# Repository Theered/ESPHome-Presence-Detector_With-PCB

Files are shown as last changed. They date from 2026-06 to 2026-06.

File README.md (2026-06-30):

# ESPHome-Presence-Detector_With-PCB
I was tired of my lights constantly turning off whenever I sat still while using a standard PIR motion detector. Since PIR sensors only detect "big movements", they often fail to notice someone who is sitting quietly.

To solve this, I built a presence detector using an mmWave sensor. Unlike a traditional PIR sensor, an mmWave sensor can detect very small movements, such as your chest moving while breathing, allowing it to reliably detect occupancy even when you're not moving around.

While designing the project, I decided to add a few extra features:

* **mmWave presence detection** for reliable occupancy sensing
* **PIR motion sensor** for fast motion detection when entering the room
* **Ambient light sensor** to prevent lights from turning on when the room is already bright
* **Status LED** to indicate Wi-Fi or device issues
* **Custom PCB** to keep the wiring clean and make assembly easier

The PCB connects all modules directly to the microcontroller, making installation as simple as plugging the sensors into their designated headers.

Sensor data is sent to Home Assistant using ESPHome, allowing you to create virtually any automation you can think of —from automatically controlling lights to sending notifications when someone enters a room, everything is possible.

## Requirements

Before starting this project, you will need:

1. A working Home Assistant server
2. A soldering iron and basic soldering skills
3. A bit of patience and a good mood ;)

**Note:** The status LED and its resistor are small and can be quite challenging to solder. If you don't care about the LED, it can be left out.

## PCB Design

schematic:


PCB:


## Design Inspiration

I wanted a clean and modern design for the detector, so i kindly asked chatGPT to make a few diffrent designes and shapes before settling on this final version:

Gemini_Generated_Image_1y6acm1y6acm1y6a

i then started modeling my own...


## Project Status

🚧 This project is still under development.

Additional documentation will be added soon, including:

* Complete assembly guide
* ESPHome configuration- and firmware instalation guide
* refined 3D-printable enclosure files

Thank you for your patience while I finish building and documenting the project.

BOM:
1. ws2812b LED
   

2. TSL2591 IIC I2C Light Sensor
   

3. ESP32 S3 C3 SuperMini Development Board
   

5. HLK-LD2410c module
   

7. AM312 PIR motion detector
   

8. Female Straight Needle Pin Header
   

9. Custom PCB (gerber files are linked in the project)


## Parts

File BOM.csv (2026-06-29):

Name | Purpose | Quantity | Total Cost (USD) | Link | Distributor
PCB | Connecting everything neatly (price includes shipping) | 1 | 4.40 |  | JLCPCB
breakable Pin Header | plugging the modules in | 1 | 2.90 | https://www.aliexpress.com/item/1005007476809536.html | Aliexpress
single ws2812b LED pixel | For showing errors and maby some smarthome integration. Pro tip: can be stolen off led strip, its cheaper | 1 | 1.55 | https://de.aliexpress.com/item/1005002657432751.html?mp=1 | Aliexpress
TSL2591 | mesuring light | 1 | 5.40 | https://www.aliexpress.com/item/1005006343708454.html | Aliexpress
ESP32 C3 SuperMini Development Board | controling the circuit | 1 | 4.40 | https://www.aliexpress.com/item/1005007941259180.html | aliexpress
ld2410c | detecting if someone is in my room reliably without turning off the light when sitting still | 1 | 5.30 | https://www.aliexpress.com/item/1005006153951413.html | Aliexpress
am312 mini | turning light on instantly instead of waiting for the slow mmwave detection | 1 | 1.80 | https://www.aliexpress.com/item/1005004616033496.html | aliexpress

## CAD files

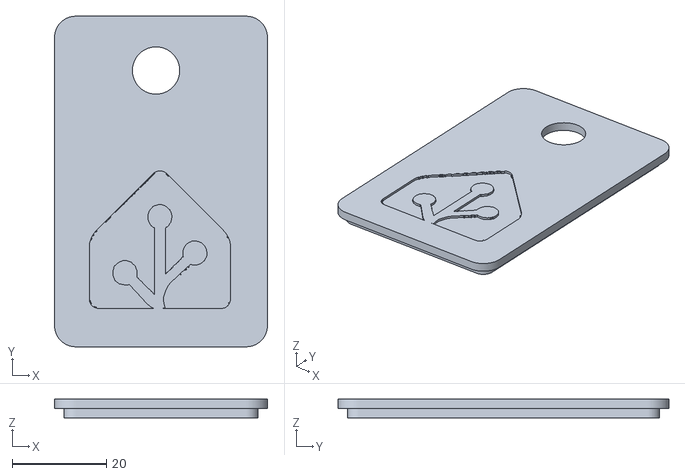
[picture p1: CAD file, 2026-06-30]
3D files/STLs/Lid.stl
45.1 x 70.0 x 4.00

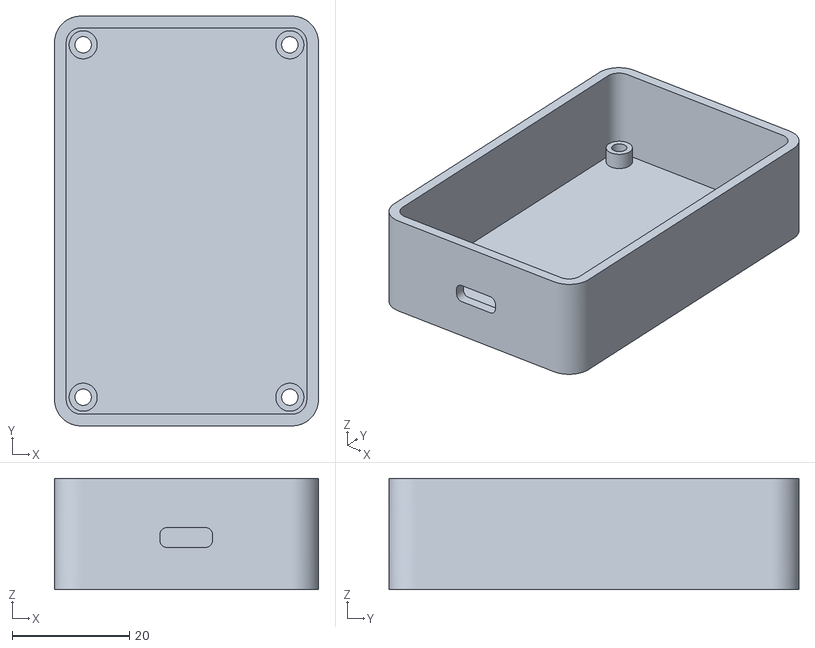
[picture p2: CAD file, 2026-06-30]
3D files/STLs/body.stl
45.1 x 70.0 x 19.0

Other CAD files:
3D files/ESPHome presence detector.f3d

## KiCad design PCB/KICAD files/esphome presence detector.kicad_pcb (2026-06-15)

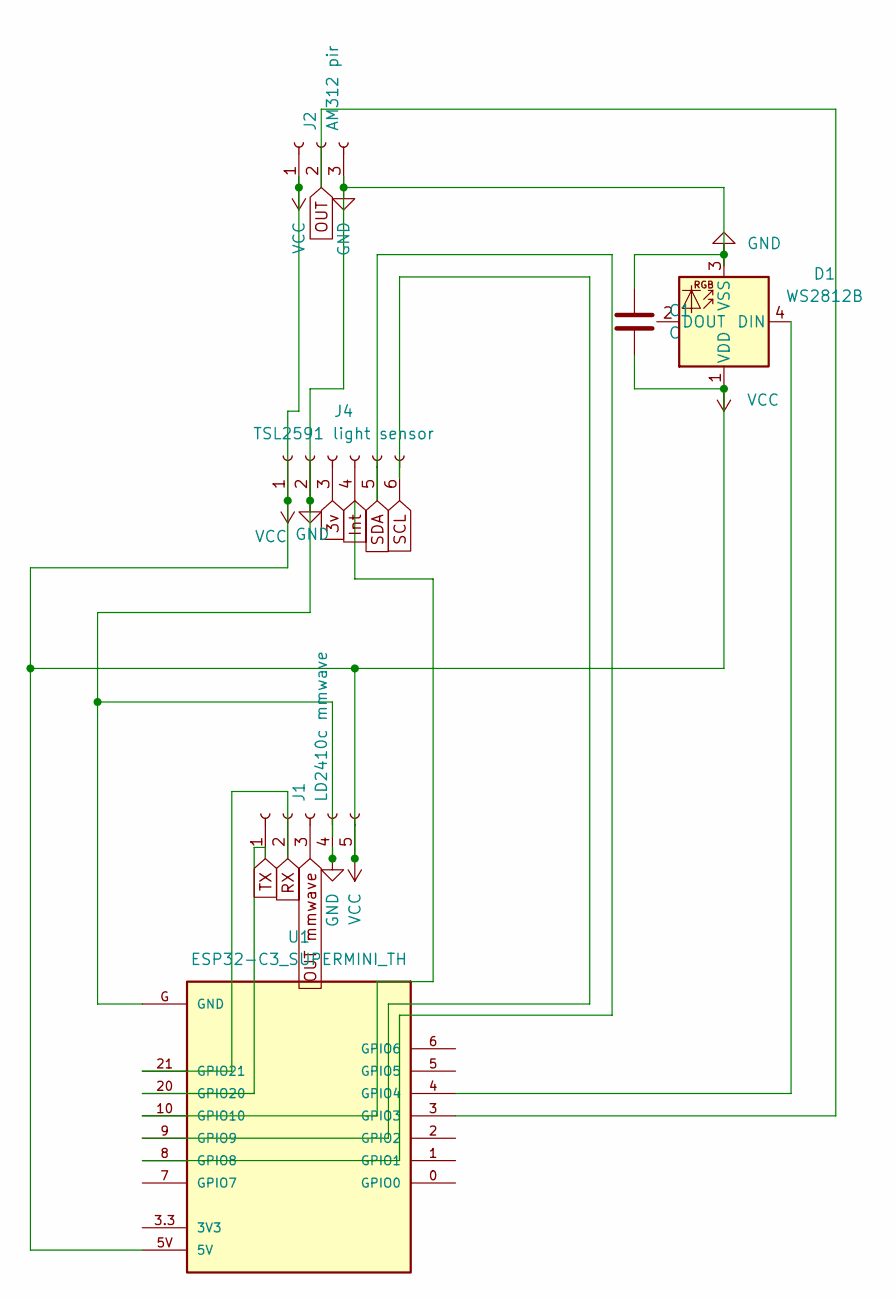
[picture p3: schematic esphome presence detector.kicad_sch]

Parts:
C1: C; C_0805_2012Metric_Pad1.18x1.45mm_HandSolder
D1: WS2812B; LED_WS2812B_PLCC4_5.0x5.0mm_P3.2mm
J1: LD2410c mmwave; PinSocket_1x05_P2.54mm_Vertical
J2: AM312 pir; PinSocket_1x03_P2.54mm_Vertical
J4: TSL2591 light sensor; PinSocket_1x06_P2.54mm_Vertical
U1: ESP32-C3_SUPERMINI_TH; MODULE_ESP32-C3_SUPERMINI_TH

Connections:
3v: J4.3
GND: C1.1, D1.3 (VSS), J1.4, J2.3, J4.2, U1.G (GND)
Int: J4.4, U1.10 (GPIO10)
unnamed: D1.4 (DIN), U1.4 (GPIO4)
OUT: J2.2, U1.3 (GPIO3)
OUT mmwave: J1.3
RX: J1.2, U1.21 (GPIO21)
SCL: J4.6
SDA: J4.5, U1.8 (GPIO8)
TX: J1.1, U1.20 (GPIO20)
VCC: C1.2, D1.1 (VDD), J1.5, J2.1, J4.1, U1.5V

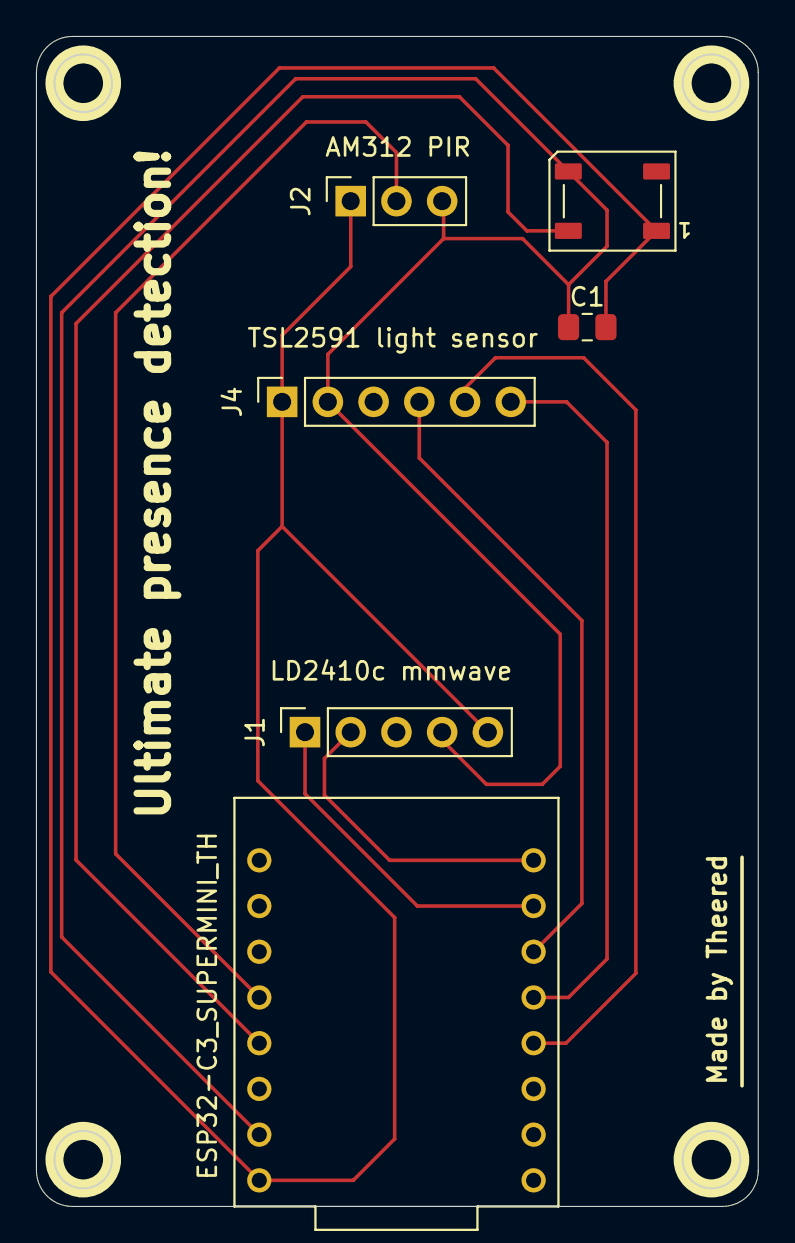
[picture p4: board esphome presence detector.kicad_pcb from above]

Board: 2 copper layers, 40.1 x 65.0 mm, 6 parts (0 on the bottom side), 8 nets.

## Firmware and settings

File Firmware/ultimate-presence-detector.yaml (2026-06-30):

# Board: ESP32-C3 Super Mini (Generic)
# Definition: definitions/boards/esp32-c3-supermini/manifest.yaml

substitutions:
  name: ultimate-presence-detector
  friendly_name: "Ultimate Presence Detector"
  
  # Pin Assignments
  pir_pin: GPIO3
  ws2812b_pin: GPIO4
  
  # I2C Pins (for TSL2591)
  i2c_sda: GPIO8
  i2c_scl: GPIO9
  
  # UART Pins (for LD2410C)
  ld2410_tx: GPIO21
  ld2410_rx: GPIO20

esphome:
  name: ${name}
  friendly_name: ${friendly_name}

esp32:
  variant: esp32c3
  flash_size: 4MB
  framework:
    type: esp-idf

logger:

api:
  encryption:
    key: "F7ViIO5/M8LV/Ve67E9GfHh85xXAf8uFSmWfIdFQUXo="

ota:
  - platform: esphome

wifi:
  ssid: !secret wifi_ssid
  password: !secret wifi_password
  ap:
    ssid: "Ultimate Presence Fallback"
    password: "ultimatepresence"

captive_portal:

# Component Buses
i2c:
  sda: ${i2c_sda}
  scl: ${i2c_scl}
  scan: true

uart:
  id: uart_bus
  tx_pin: ${ld2410_tx}
  rx_pin: ${ld2410_rx}
  baud_rate: 256000

ld2410:

binary_sensor:
  # AM312 PIR
  - platform: gpio
    pin: ${pir_pin}
    name: "PIR Motion"
    device_class: motion

  # LD2410
  - platform: ld2410
    has_target:
      name: "LD2410 Presence"
    has_moving_target:
      name: "LD2410 Moving Target"
    has_still_target:
      name: "LD2410 Still Target"

sensor:
  # TSL2591 Light Sensor
  - platform: tsl2591
    name: "Illuminance"
    id: tsl2591_illuminance
    address: 0x29
    update_interval: 60s
    full_spectrum:
      name: "Full Spectrum"
    infrared:
      name: "Infrared"
    visible:
      name: "Visible Light"

  # LD2410
  - platform: ld2410
    moving_distance:
      name: "Moving Distance"
    still_distance:
      name: "Still Distance"
    moving_energy:
      name: "Moving Energy"
    still_energy:
      name: "Still Energy"
    detection_distance:
      name: "Detection Distance"

# WS2812B Status LED
light:
  - platform: esp32_rmt_led_strip
    chipset: WS2812
    rgb_order: GRB
    pin: ${ws2812b_pin}
    num_leds: 1
    name: "Status LED"
    id: status_led
